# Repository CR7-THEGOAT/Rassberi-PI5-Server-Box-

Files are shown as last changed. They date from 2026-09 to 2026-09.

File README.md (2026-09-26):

# Rassberi-PI5-Server-Box-

This is a modular Raspberry Pi 5 five-bay NAS/server enclosure: a 240 × 145 × 102 main shell with 3 mm walls and floor. It has five front-loading 2.5-inch HDD/SSD trays on the left and the Raspberry Pi 5/N07 NVMe area on the right. The lid slides out through the front on guided rails; it is not a fixed screw-on lid.
The Pi 5 is mounted with its USB-C power and two Micro-HDMI ports facing the front wall, and its Ethernet plus four USB-A ports facing the right wall. No Pi ports are placed on the top.
Wall	Pi 5 opening	Case cutout
Front	USB-C power	11.5 × 5.5 capsule opening, with a larger 13.2 × 7.3 × 2.4 deep outer recess for thick USB-C plug housings
Front	Micro-HDMI 0	9.5 × 6.5 opening
Front	Micro-HDMI 1	9.5 × 6.5 opening
Right side	Gigabit Ethernet RJ45	16.0 × 13.5 opening
Right side	2× USB 3.0 Type-A	Two separate 14.0 × 6.6 openings
Right side	2× USB 2.0 Type-A	Two separate 14.0 × 6.6 openings

From left to right along the Pi front edge, the ports are USB-C, Micro-HDMI 0, then Micro-HDMI 1. Their PCB-datum centre positions are 11.2 mm, 25.8 mm, and 39.2 mm, so the HDMI and USB-C openings stay close together like the real Pi 5.
The Raspberry Pi 5 board footprint used by the model is 85 × 56 mm with a 1.336 mm PCB datum. The enclosure supports the real Pi 5 port set: one USB-C power input, two Micro-HDMI display outputs, one Gigabit Ethernet port, two USB 3.0 ports, and two USB 2.0 ports. The Pi 5 itself has a quad-core 2.4 GHz Cortex-A76 processor, dual 4Kp60 Micro-HDMI capability, PCIe 2.0 x1, microSD, Wi-Fi/Bluetooth, GPIO, and MIPI connectors. Raspberry Pi recommends proper cooling and a 5 V/5 A USB-C supply for sustained loads. Official Pi 5 specifications
Under the Pi is an allowance for your GeeekPi N07 MiniTower NVMe adapter using its original brass spacers. The N07 board is only a fit reference and is not included as printable geometry. Its allocated bay is 4 inches / 101.6 mm long—not 4 inches tall. The under-Pi area uses a compact 10 mm SSD/underside allowance, a 7 mm Pi-to-N07 spacer gap, and places the Pi PCB underside about 21.6 mm above the case floor.
The storage side has five individual 2.5-inch drive trays:
- Each tray uses a 78 mm guide channel and a 76.7 mm printed tray body.
- Tray depth is 108 mm.
- It supports 7, 9.5, 12.5, and 15 mm thick 2.5-inch HDDs or SSDs.
- Each tray has a solid front panel with a permanently fused, rounded U-pull handle—no centre hole.
- The handle uses a 7 mm round bar, 44 mm post spacing, an 11 mm finger gap, and projects about 20.5 mm forward.
- The rear includes a 54 × 16 mm pass-through and cable corridor for the VCOM USB 3.0-to-SATA adapter head; the VCOM cable itself is not printed.
Cooling is built into the shell:
- One large top exhaust opening sized around a 74 mm clear diameter for an 80 mm-class fan.
- One retained auxiliary top fan opening.
- One right-side Pi/electronics intake opening with a 36 mm clear bore and 44 mm outer ring.
- Side ventilation slots by the drive cage.
- Fans are not included as printed solids.
The lid includes a generic 120 × 75 mm support frame for a 5-inch display. The small centred screen cable circle is removed and filled solid. The former rear five-port Ethernet-board compartment, its five RJ45 holes, 12 V round jack hole, and large rear capacitor/air opening are also removed. The normal single Pi 5 Ethernet opening on the right side remains.
The complete editable source is in one file: [REV27 Pi 5 server-box source](C:/Users/saeed/Documents/Codex/2026-09-13/this-is-almost-perfect-almost-see/outputs/REV27_NO_CIRCLE_NO_REAR_ETHERNET/Server_Box_REV27_NO_CIRCLE_NO_REAR_ETHERNET.scad). Set part to base, top, or tray to export the individual printable parts; assembly is only for viewing the complete layout. The packaged release

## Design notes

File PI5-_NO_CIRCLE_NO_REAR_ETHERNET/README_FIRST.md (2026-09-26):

# REV27 — no small lid circle and no rear Ethernet-board box

This is a separate complete version. It keeps the REV26 body size, removable slide lid, Raspberry Pi side ports, five storage bays, VCOM adapter clearance, and the latest solid-front U-handle trays.

## Removed in REV27

- The small centred 1-inch circle in the lid is filled; the lid is solid there.
- The separate rear five-port Ethernet-board compartment is removed.
- Its internal support, rear RJ45 openings, 12 V round power opening, and the Ethernet-board air/capacitor opening are all closed, leaving a continuous rear wall.

## Still present

- The normal Raspberry Pi Ethernet plus four USB-A openings on the right side.
- The Pi USB-C and two Micro-HDMI openings.
- The solid-front trays with attached round U-pull handles.

## Use

`Server_Box_REV27_NO_CIRCLE_NO_REAR_ETHERNET_ASSEMBLY.stl` is one complete assembled-view file. It has seven disconnected components inside it, so do not print it as one piece.

Print `base_REV27.stl` once, `top_REV27_slide_lid.stl` once, and `tray_REV27_U_Pull.stl` five times.

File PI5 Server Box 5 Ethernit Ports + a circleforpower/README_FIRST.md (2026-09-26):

# REV26 — complete all-new model

This is the single current version of the complete Raspberry Pi 5 server box. It includes the latest body and port layout, the removable slide-out lid, the five storage bays, the rear VCOM USB-to-SATA adapter clearance, and the latest solid-front trays with attached round U-shaped handles.

## One file that shows everything

**`Server_Box_REV26_ALL_NEW_ASSEMBLY.stl`** contains the base, lid, and all five latest trays together in their correct assembled positions. Use it to inspect the entire finished model in your slicer or 3D viewer.

It has seven disconnected printable components inside one STL, so do **not** slice it as one print-in-place object.

## Files to print

- `base_REV26.stl` — print once.
- `top_REV26_slide_lid.stl` — print once.
- `tray_REV26_U_Pull.stl` — print five copies, one per drive bay.

## Latest tray details

- Solid front panel: there is no center hole through the tray face.
- Real surface-mounted U pull: round 7 mm bar, two rounded end mounts, and approximately 11 mm finger clearance behind the bar.
- Each handle is fused to its tray as one watertight printable solid.

## Included source

`Server_Box_REV26_ALL_NEW.scad` is the full editable OpenSCAD source with `part = "base"`, `"top"`, `"tray"`, or `"assembly"` support.

No GeeekPi case or fan is included as printable geometry. Test one tray in your printed base before printing all five.

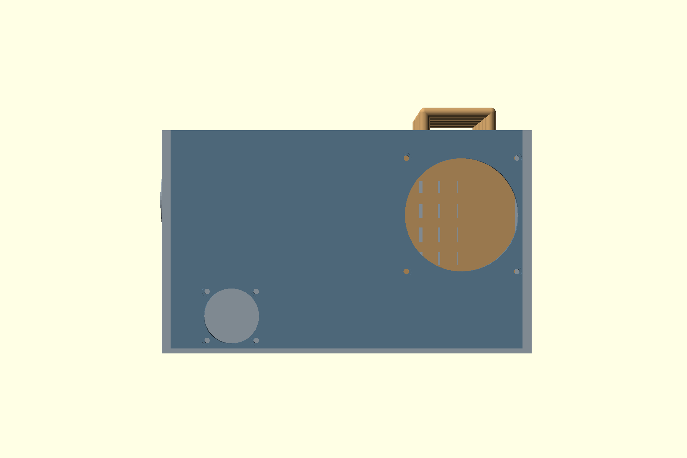
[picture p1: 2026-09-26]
PI5-_NO_CIRCLE_NO_REAR_ETHERNET/REV27_REAR_CLOSED_PREVIEW.png

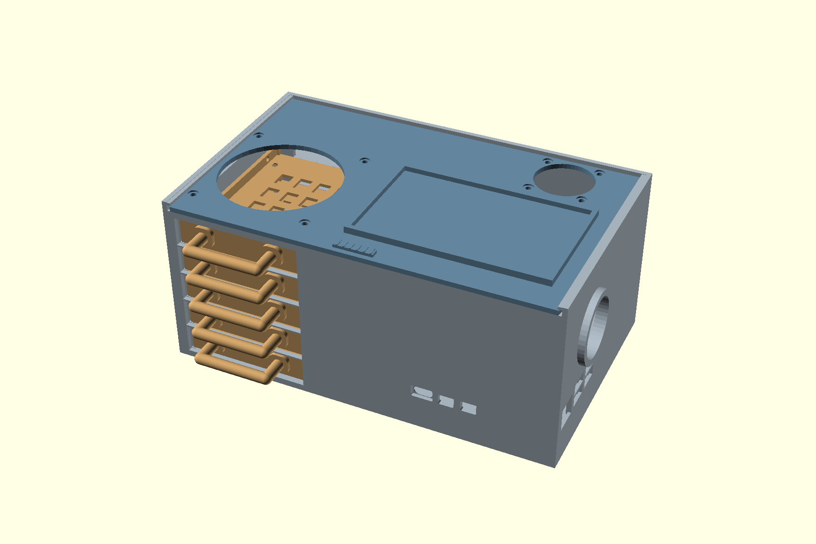
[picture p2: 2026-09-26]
PI5-_NO_CIRCLE_NO_REAR_ETHERNET/REV27_NO_CIRCLE_NO_REAR_ETHERNET_PREVIEW.png

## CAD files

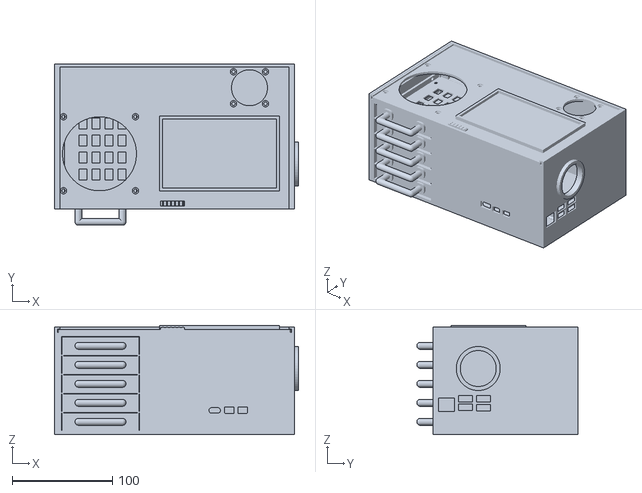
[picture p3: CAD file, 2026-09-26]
PI5-_NO_CIRCLE_NO_REAR_ETHERNET/Server_Box_REV27_NO_CIRCLE_NO_REAR_ETHERNET_ASSEMBLY.stl
244.0 x 161.5 x 109.0

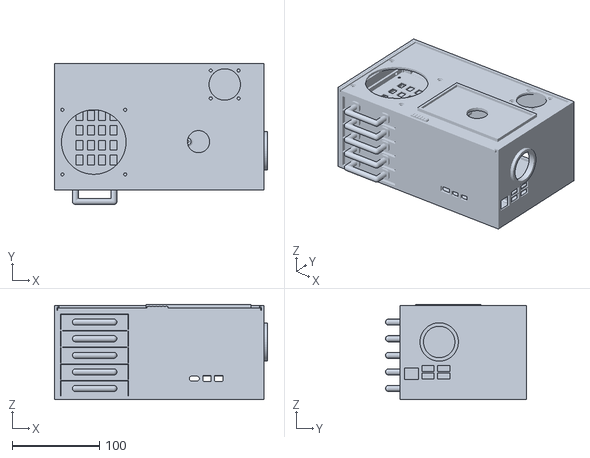
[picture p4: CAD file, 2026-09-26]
PI5 Server Box 5 Ethernit Ports + a circleforpower/Server_Box_REV26_ALL_NEW_ASSEMBLY.stl
244.0 x 161.5 x 109.0

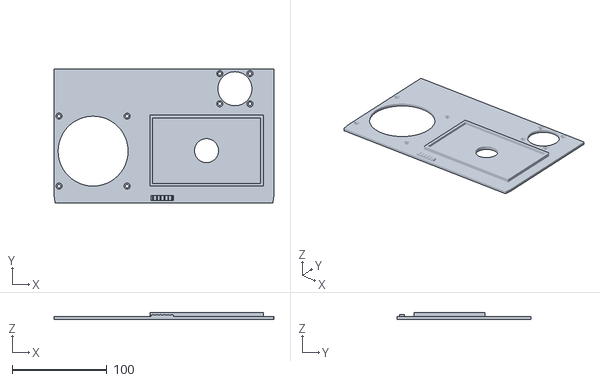
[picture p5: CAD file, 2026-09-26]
PI5 Server Box 5 Ethernit Ports + a circleforpower/top_REV26_slide_lid.stl
232.7 x 142.0 x 7.00

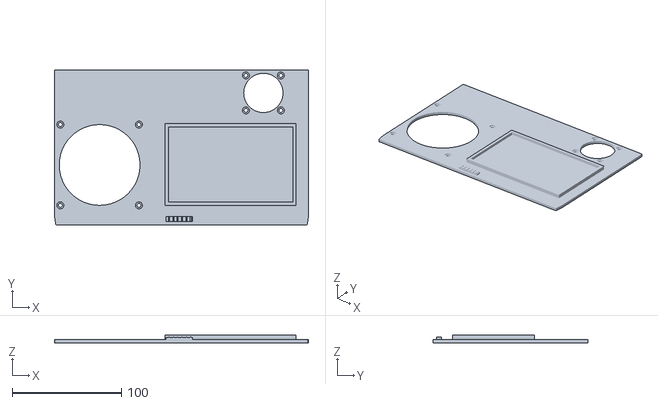
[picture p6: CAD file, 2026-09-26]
PI5-_NO_CIRCLE_NO_REAR_ETHERNET/top_REV27_slide_lid.stl
232.7 x 142.0 x 7.00

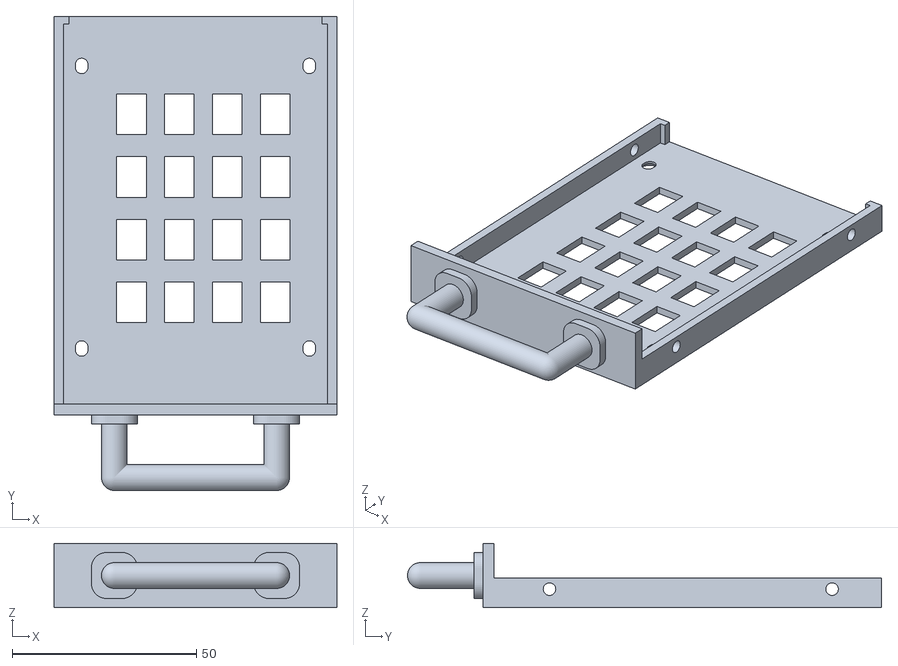
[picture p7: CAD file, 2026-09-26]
PI5 Server Box 5 Ethernit Ports + a circleforpower/tray_REV26_U_Pull.stl
76.7 x 128.5 x 17.4

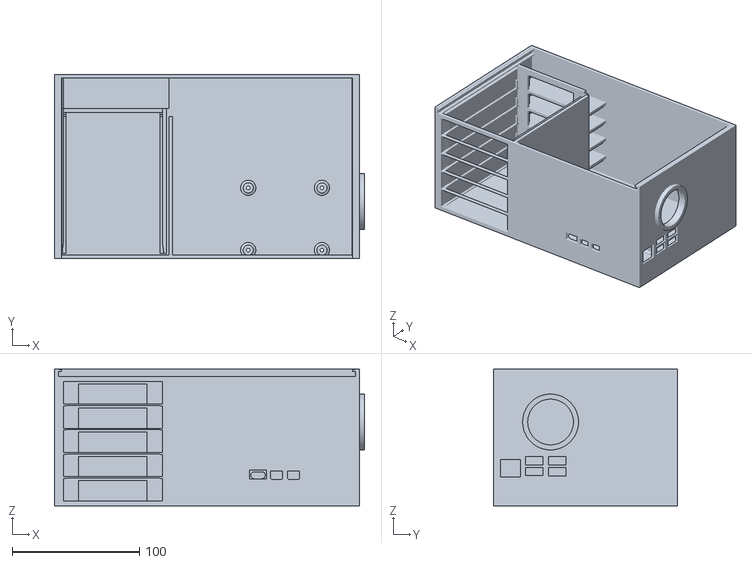
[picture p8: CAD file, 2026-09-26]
PI5-_NO_CIRCLE_NO_REAR_ETHERNET/base_REV27.stl
244.0 x 145.0 x 107.6

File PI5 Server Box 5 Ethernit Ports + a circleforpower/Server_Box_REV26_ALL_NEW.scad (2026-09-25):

// Raspberry Pi 5 five-bay slide-in HDD/SSD enclosure
// REVISION 26: REV25 fit retained; front is solid and the pull is a two-post,
// round U-handle like a surface-mounted drawer pull. No centre opening remains.
// REV19 port geometry, REV18 USB-C recess and compact Pi/N07 remain intact.
// Opening B remains filled. Original body, lid and tray geometry preserved
// Body, lid, trays and four-inch LENGTH allowance retained.
// Units: millimetres. Hardware fit-check prototype; check real cables/HAT.
// Original rev10 is preserved. No reference electronics are printable solids.
//
// Drive orientation: 2.5-inch drive long edge runs front-to-back so the
// SATA connector is at the rear. Each tray slides in from the front.
// The 24 mm rear chase is intentionally reserved for SATA data/power wiring.

part = "assembly"; // "base", "top", "tray", or "assembly"
$fn = 48;
lid_slide = 0; // negative Y slides the lid out through the FRONT
tray_slide = 0; // negative Y shows all five drive trays pulled out in preview
remove_aux_top_fan = false; // A is retained; owner selected B for removal

body_x = 240;
body_y = 145;
body_z = 102;
wall = 3;
floor = 3;

tray_x = 78;        // 70 mm drive width + print clearance
tray_y = 108;       // 100 mm drive length + clearance
tray_x0 = 7;
tray_y0 = 4;        // front stop remains reachable through the front opening
tray_pitch = 19;    // supports 7, 9.5, 12.5, and 15 mm drives
bay_z0 = 4;
drive_opening_h = 18;
// The VCOM CU815-class SATA-to-USB head is roughly 45 mm wide and 11 mm
// thick.  Give it a proper per-drive rear pass-through and an open corridor;
// the cable/adapter remains real hardware, never printable model geometry.
cable_lane_h = 16;
vcom_adapter_head_w = 45;
vcom_adapter_head_h = 11;
vcom_adapter_head_depth = 25;
vcom_adapter_clear_each_side = 4.5;
vcom_adapter_slot_w = vcom_adapter_head_w+2*vcom_adapter_clear_each_side; // 54
vcom_adapter_slot_h = 16;
vcom_adapter_corridor_d = 30;
drive_nominal_l = 100;
// A standard 2.5-inch drive starts 4 mm behind the tray face.  Its VCOM head
// therefore begins at global Y=108 mm and can run to Y=138 mm before the rear
// wall's 3 mm thickness begins at Y=142 mm.
vcom_adapter_corridor_y0 = tray_y0+4+drive_nominal_l;
assert(vcom_adapter_slot_w < tray_x,
       "VCOM adapter opening must leave structural side posts");
assert(vcom_adapter_slot_h < tray_pitch,
       "VCOM adapter opening must retain the bay separator");
assert(vcom_adapter_corridor_y0+vcom_adapter_corridor_d <= body_y-wall,
       "VCOM adapter must stay inside the rear cable chase");

// REV20 sliding fit: values are independent so a tray change never alters
// the lid or port locations. REV19 used 0.3 mm per side and a floating
// 0.3 mm rail gap; that could bind after FDM print tolerances.
tray_slide_side_clearance = 0.65;
tray_slide_entry_len = 8;
tray_guide_w = 3;
tray_guide_front_w = 1.8; // entry funnel opens an extra 1.2 mm each side
tray_guide_h = 96;
tray_rail_outer_overlap = 0.6; // mechanically joins each rail to its guide
tray_rail_inward = 2.0;
tray_rail_w = tray_rail_outer_overlap+tray_rail_inward; // 2.6 mm
tray_rail_h = 1.4;
tray_rail_entry_drop = 0.6; // gentle lower rail lead-in, then seated contact
tray_end_stop_t = 1.5;
tray_end_stop_h = 8;
tray_front_top_clearance = 0.6;
tray_seated_x = tray_x0+tray_slide_side_clearance;
tray_seated_z = bay_z0; // tray floor rests on the rail top; not floating

// REV26: Surface-mounted U pull handle. Two rounded mount pads overlap the
// solid front wall; two round standoffs support a smooth horizontal bar. It is
// one printable piece, with a real 11 mm finger gap behind the bar.
tray_u_handle_post_spacing = 44;
tray_u_handle_tube_r = 3.5;
tray_u_handle_mount_w = 12.5;
tray_u_handle_mount_h = 12.5;
tray_u_handle_mount_corner_r = 4.2;
tray_u_handle_mount_depth = 2.5;
tray_u_handle_outer_reach = 20.5; // front-most point from the body face

// The removable lid uses the same printable side clearance and a narrower
// first 8 mm, so it finds the channel instead of scraping both walls.
lid_slide_side_clearance = 0.65;
lid_slide_entry_len = 8;
lid_slide_entry_inset = 1.2;
lid_plate_x0 = wall+lid_slide_side_clearance;
lid_plate_w = body_x-2*lid_plate_x0;
lid_plate_y = body_y-wall; // rear edge meets the existing rear stop

drive_back_y = 115; // end of drive cage
chase_start_y = 118;
// The old 120 mm separators intersected the separate Ethernet PCB.
cable_lane_width_safe = 83;
// Owner clarified: 4 inches is the N07 LENGTH ALLOWANCE, not PCB size.
// Actual board dimensions and a separately reserved bay are defined below.
port_depth = 25.4;  // 1 inch internal connector clearance
// Measured five-port Ethernet board: 103 x 73 mm, 5 mm PCB/underside,
// 16 mm total board/metal/component height, and a 2-inch rear air keepout.
board_x0 = 105;
board_y0 = 66;
board_l = 103;
board_w = 73;
board_base_z = 8;
pcb_total_t = 5;
ethernet_board_height = 16;
rj45_bank_x = 132;
rj45_bank_w = 73;
rj45_bank_z = board_base_z;
rj45_bank_h = 21;
rj45_external_x = 132;
// User-specified Ethernet envelope: 16 x 15 x 21 mm (L x W x H).
// The visible face is kept at 14 mm per the requested opening dimension.
ethernet_port_length = 16;
ethernet_port_depth = 15;
ethernet_port_height = 21;
ethernet_opening_w = 14;
ethernet_opening_z = 6;
rj45_external_w = ethernet_opening_w;
rj45_external_z = ethernet_opening_z;
rj45_external_h = ethernet_port_height;
// Five lower RJ45 openings line up with the five-port board.  The round
// spare hole remains separate and is not converted to Ethernet.
rj45_port_slots = [
    [132, ethernet_opening_z, ethernet_opening_w, ethernet_port_height],
    [146, ethernet_opening_z, ethernet_opening_w, ethernet_port_height],
    [160, ethernet_opening_z, ethernet_opening_w, ethernet_port_height],
    [174, ethernet_opening_z, ethernet_opening_w, ethernet_port_height],
    [188, ethernet_opening_z, ethernet_opening_w, ethernet_port_height]
];
// Power circle moved to the opposite side of the lower Ethernet row.
// The row ends at x=202; 3 mm clearance plus the 5.5 mm radius gives 210.5.
dc_jack_x = 210.5;
dc_jack_clear_d = 17;
dc_jack_z = board_base_z + dc_jack_clear_d/2;
dc_jack_r = 5.5; // approx. 11 mm circular barrel-jack opening
cap_keep_height = 50.8; // 2 in air-conditioning clearance
// REV12: the former square openings at [108,100,14,14] and
// [125,100,14,14] are deleted. That lid region is solid, 3 mm thick.
// Separate top-entry Ethernet/12V routing is no longer provided there.
spare_air_hole_x = 209;
spare_air_hole_z = ethernet_opening_z + ethernet_port_height + 3 + 25.4;
spare_air_hole_r = 25.4; // 2 in diameter, enlarged from the 1.8 in request
screen_x0 = 105;
screen_y0 = 18;
screen_w = 120;
screen_h = 75;
// Shared PCB datum, measured from official RP-010083-CA-1 STEP (May 2026).
// STEP board underside Z=0; copper top Z=1.336. No reference CAD imported.
// The owner approved removing the former two-inch under-Pi height reserve.
// An 8 mm SSD/underside design envelope plus 2 mm floor clearance sets the
// N07 seat. This is a design allowance, not a measured SSD/heatsink height.
pi_x = 149;
pi_y = 3.2;
// N07 only: no kit case, cooler, fan, display or reference PCB is printed.
// Manufacturer EP-0211 mechanical drawing: 87.5 x 56 x 1.6 mm PCB.
// ZP-0187 kit hardware sheet: M2.5 x 7+6 mm inter-board posts.
// Owner confirmed ORIGINAL KIT spacers. Standalone N07's 6 mm spacing
// must not be substituted for this kit-specific nominal 7 mm gap.
n07_l = 87.5;
n07_w = 56;
n07_bay_length = 101.6; // 4 inches reserved for N07, not a scaled board
n07_bay_x1 = body_x-wall; // inside right wall X=237
n07_bay_x0 = n07_bay_x1-n07_bay_length; // X=135.4
// 13.6 mm length allowance left of PCB and 0.5 mm to its right.
// Bay is an allocated keepout, not extra printed walls. Mounts occupy it.
assert(pi_x >= n07_bay_x0 && pi_x+n07_l <= n07_bay_x1,
       "N07 PCB must fit within its four-inch allocated length");
n07_pcb_t = 1.6;
n07_pi_gap = 7;
ssd_underside_envelope_h = 8;
ssd_floor_gap = 2;
n07_support_h = ssd_underside_envelope_h+ssd_floor_gap; // 10 mm
n07_under_z = floor+n07_support_h; // seat Z=13
n07_top_z = n07_under_z+n07_pcb_t; // 14.6
pi_pcb_under_z = n07_top_z+n07_pi_gap; // 21.6
pi_pcb_t = 1.336; // reference model, NOT a universal production tolerance
pi_pcb_top_z = pi_pcb_under_z+pi_pcb_t;
n07_post_d = 8;
n07_foot_d = 12;
n07_neck_h = 8; // narrow support alongside the SSD design envelope
n07_taper_h = 1; // plus 1 mm straight foot, below the SSD keepout
assert(n07_support_h > n07_neck_h+n07_taper_h,
       "Support must retain a positive-height foot");
n07_head_access_d = 5.6; // long screwdriver / M2.5 screw-head passage
n07_screw_clear_d = 2.8;
n07_seat_t = 2;
// M2.5 x 6 screws pass up through 2 mm plastic and 1.6 mm N07 PCB,
// leaving nominal 2.4 mm engagement into original spacer's female end.
// Fit-test actual heads, spacers and printer tolerances before final use.
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

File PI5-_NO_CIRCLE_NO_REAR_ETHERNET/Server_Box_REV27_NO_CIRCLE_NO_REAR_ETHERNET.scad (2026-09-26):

// Raspberry Pi 5 five-bay slide-in HDD/SSD enclosure
// REVISION 27: REV26 fit retained; the small centred lid circle and the
// separate five-port Ethernet-board compartment at the rear are removed.
// REV19 port geometry, REV18 USB-C recess and compact Pi/N07 remain intact.
// Opening B remains filled. Original body, lid and tray geometry preserved
// Body, lid, trays and four-inch LENGTH allowance retained.
// Units: millimetres. Hardware fit-check prototype; check real cables/HAT.
// Original rev10 is preserved. No reference electronics are printable solids.
//
// Drive orientation: 2.5-inch drive long edge runs front-to-back so the
// SATA connector is at the rear. Each tray slides in from the front.
// The 24 mm rear chase is intentionally reserved for SATA data/power wiring.

part = "assembly"; // "base", "top", "tray", or "assembly"
$fn = 48;
lid_slide = 0; // negative Y slides the lid out through the FRONT
tray_slide = 0; // negative Y shows all five drive trays pulled out in preview
remove_aux_top_fan = false; // A is retained; owner selected B for removal
remove_small_lid_circle = true; // owner requested a lid without this opening
remove_rear_ethernet_box = true; // preserves normal Pi Ethernet/USB side ports

body_x = 240;
body_y = 145;
body_z = 102;
wall = 3;
floor = 3;

tray_x = 78;        // 70 mm drive width + print clearance
tray_y = 108;       // 100 mm drive length + clearance
tray_x0 = 7;
tray_y0 = 4;        // front stop remains reachable through the front opening
tray_pitch = 19;    // supports 7, 9.5, 12.5, and 15 mm drives
bay_z0 = 4;
drive_opening_h = 18;
// The VCOM CU815-class SATA-to-USB head is roughly 45 mm wide and 11 mm
// thick.  Give it a proper per-drive rear pass-through and an open corridor;
// the cable/adapter remains real hardware, never printable model geometry.
cable_lane_h = 16;
vcom_adapter_head_w = 45;
vcom_adapter_head_h = 11;
vcom_adapter_head_depth = 25;
vcom_adapter_clear_each_side = 4.5;
vcom_adapter_slot_w = vcom_adapter_head_w+2*vcom_adapter_clear_each_side; // 54
vcom_adapter_slot_h = 16;
vcom_adapter_corridor_d = 30;
drive_nominal_l = 100;
// A standard 2.5-inch drive starts 4 mm behind the tray face.  Its VCOM head
// therefore begins at global Y=108 mm and can run to Y=138 mm before the rear
// wall's 3 mm thickness begins at Y=142 mm.
vcom_adapter_corridor_y0 = tray_y0+4+drive_nominal_l;
assert(vcom_adapter_slot_w < tray_x,
       "VCOM adapter opening must leave structural side posts");
assert(vcom_adapter_slot_h < tray_pitch,
       "VCOM adapter opening must retain the bay separator");
assert(vcom_adapter_corridor_y0+vcom_adapter_corridor_d <= body_y-wall,
       "VCOM adapter must stay inside the rear cable chase");

// REV20 sliding fit: values are independent so a tray change never alters
// the lid or port locations. REV19 used 0.3 mm per side and a floating
// 0.3 mm rail gap; that could bind after FDM print tolerances.
tray_slide_side_clearance = 0.65;
tray_slide_entry_len = 8;
tray_guide_w = 3;
tray_guide_front_w = 1.8; // entry funnel opens an extra 1.2 mm each side
tray_guide_h = 96;
tray_rail_outer_overlap = 0.6; // mechanically joins each rail to its guide
tray_rail_inward = 2.0;
tray_rail_w = tray_rail_outer_overlap+tray_rail_inward; // 2.6 mm
tray_rail_h = 1.4;
tray_rail_entry_drop = 0.6; // gentle lower rail lead-in, then seated contact
tray_end_stop_t = 1.5;
tray_end_stop_h = 8;
tray_front_top_clearance = 0.6;
tray_seated_x = tray_x0+tray_slide_side_clearance;
tray_seated_z = bay_z0; // tray floor rests on the rail top; not floating

// REV26: Surface-mounted U pull handle. Two rounded mount pads overlap the
// solid front wall; two round standoffs support a smooth horizontal bar. It is
// one printable piece, with a real 11 mm finger gap behind the bar.
tray_u_handle_post_spacing = 44;
tray_u_handle_tube_r = 3.5;
tray_u_handle_mount_w = 12.5;
tray_u_handle_mount_h = 12.5;
tray_u_handle_mount_corner_r = 4.2;
tray_u_handle_mount_depth = 2.5;
tray_u_handle_outer_reach = 20.5; // front-most point from the body face

// The removable lid uses the same printable side clearance and a narrower
// first 8 mm, so it finds the channel instead of scraping both walls.
lid_slide_side_clearance = 0.65;
lid_slide_entry_len = 8;
lid_slide_entry_inset = 1.2;
lid_plate_x0 = wall+lid_slide_side_clearance;
lid_plate_w = body_x-2*lid_plate_x0;
lid_plate_y = body_y-wall; // rear edge meets the existing rear stop

drive_back_y = 115; // end of drive cage
chase_start_y = 118;
// The old 120 mm separators intersected the separate Ethernet PCB.
cable_lane_width_safe = 83;
// Owner clarified: 4 inches is the N07 LENGTH ALLOWANCE, not PCB size.
// Actual board dimensions and a separately reserved bay are defined below.
port_depth = 25.4;  // 1 inch internal connector clearance
// Measured five-port Ethernet board: 103 x 73 mm, 5 mm PCB/underside,
// 16 mm total board/metal/component height, and a 2-inch rear air keepout.
board_x0 = 105;
board_y0 = 66;
board_l = 103;
board_w = 73;
board_base_z = 8;
pcb_total_t = 5;
ethernet_board_height = 16;
rj45_bank_x = 132;
rj45_bank_w = 73;
rj45_bank_z = board_base_z;
rj45_bank_h = 21;
rj45_external_x = 132;
// User-specified Ethernet envelope: 16 x 15 x 21 mm (L x W x H).
// The visible face is kept at 14 mm per the requested opening dimension.
ethernet_port_length = 16;
ethernet_port_depth = 15;
ethernet_port_height = 21;
ethernet_opening_w = 14;
ethernet_opening_z = 6;
rj45_external_w = ethernet_opening_w;
rj45_external_z = ethernet_opening_z;
rj45_external_h = ethernet_port_height;
// Five lower RJ45 openings line up with the five-port board.  The round
// spare hole remains separate and is not converted to Ethernet.
rj45_port_slots = [
    [132, ethernet_opening_z, ethernet_opening_w, ethernet_port_height],
    [146, ethernet_opening_z, ethernet_opening_w, ethernet_port_height],
    [160, ethernet_opening_z, ethernet_opening_w, ethernet_port_height],
    [174, ethernet_opening_z, ethernet_opening_w, ethernet_port_height],
    [188, ethernet_opening_z, ethernet_opening_w, ethernet_port_height]
];
// Power circle moved to the opposite side of the lower Ethernet row.
// The row ends at x=202; 3 mm clearance plus the 5.5 mm radius gives 210.5.
dc_jack_x = 210.5;
dc_jack_clear_d = 17;
dc_jack_z = board_base_z + dc_jack_clear_d/2;
dc_jack_r = 5.5; // approx. 11 mm circular barrel-jack opening
cap_keep_height = 50.8; // 2 in air-conditioning clearance
// REV12: the former square openings at [108,100,14,14] and
// [125,100,14,14] are deleted. That lid region is solid, 3 mm thick.
// Separate top-entry Ethernet/12V routing is no longer provided there.
spare_air_hole_x = 209;
spare_air_hole_z = ethernet_opening_z + ethernet_port_height + 3 + 25.4;
spare_air_hole_r = 25.4; // 2 in diameter, enlarged from the 1.8 in request
screen_x0 = 105;
screen_y0 = 18;
screen_w = 120;
screen_h = 75;
// Shared PCB datum, measured from official RP-010083-CA-1 STEP (May 2026).
// STEP board underside Z=0; copper top Z=1.336. No reference CAD imported.
// The owner approved removing the former two-inch under-Pi height reserve.
// An 8 mm SSD/underside design envelope plus 2 mm floor clearance sets the
// N07 seat. This is a design allowance, not a measured SSD/heatsink height.
pi_x = 149;
pi_y = 3.2;
// N07 only: no kit case, cooler, fan, display or reference PCB is printed.
// Manufacturer EP-0211 mechanical drawing: 87.5 x 56 x 1.6 mm PCB.
// ZP-0187 kit hardware sheet: M2.5 x 7+6 mm inter-board posts.
// Owner confirmed ORIGINAL KIT spacers. Standalone N07's 6 mm spacing
// must not be substituted for this kit-specific nominal 7 mm gap.
n07_l = 87.5;
n07_w = 56;
n07_bay_length = 101.6; // 4 inches reserved for N07, not a scaled board
n07_bay_x1 = body_x-wall; // inside right wall X=237
n07_bay_x0 = n07_bay_x1-n07_bay_length; // X=135.4
// 13.6 mm length allowance left of PCB and 0.5 mm to its right.
// Bay is an allocated keepout, not extra printed walls. Mounts occupy it.
assert(pi_x >= n07_bay_x0 && pi_x+n07_l <= n07_bay_x1,
       "N07 PCB must fit within its four-inch allocated length");
n07_pcb_t = 1.6;
n07_pi_gap = 7;
ssd_underside_envelope_h = 8;
ssd_floor_gap = 2;
n07_support_h = ssd_underside_envelope_h+ssd_floor_gap; // 10 mm
n07_under_z = floor+n07_support_h; // seat Z=13
n07_top_z = n07_under_z+n07_pcb_t; // 14.6
pi_pcb_under_z = n07_top_z+n07_pi_gap; // 21.6
pi_pcb_t = 1.336; // reference model, NOT a universal production tolerance
pi_pcb_top_z = pi_pcb_under_z+pi_pcb_t;
n07_post_d = 8;
n07_foot_d = 12;
n07_neck_h = 8; // narrow support alongside the SSD design envelope
n07_taper_h = 1; // plus 1 mm straight foot, below the SSD keepout
assert(n07_support_h > n07_neck_h+n07_taper_h,
       "Support must retain a positive-height foot");
n07_head_access_d = 5.6; // long screwdriver / M2.5 screw-head passage
n07_screw_clear_d = 2.8;
n07_seat_t = 2;
// M2.5 x 6 screws pass up through 2 mm plastic and 1.6 mm N07 PCB,
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

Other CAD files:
PI5 Server Box 5 Ethernit Ports + a circleforpower/base_REV26.stl
PI5-_NO_CIRCLE_NO_REAR_ETHERNET/tray_REV27_U_Pull.stl
